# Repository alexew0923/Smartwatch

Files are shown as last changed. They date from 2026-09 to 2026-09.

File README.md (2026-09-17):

# Smartch
This repository contains all the files for the smartwatch and it is participating in the Stardance Challenge by Hack Club.

# Components Used
Components are bought from DigiKey, AliExpress and Amazon
- XIAO ESP32C3 (main processor)
- 450mAh LiPo Battery with PH 2.0 mm JST Connector
- PH 2.0 mm JST Connector
- 4 x 100nF 0603_1608 Capacitors (DigiKey part number: 1276-1005-1-ND)
- 1.28 inch Round TFT Display (with pin sockets)
- DS3231 RTC Module (with pin headers)
- 6 x 10k 0603_1608 Resistors (DigiKey part number: 311-10.0KHRCT-ND)
- 4 x 4.7k 0603_1608 Resistors (DigiKey part number: 311-4.70KHRCT-ND)
- 2 x Tactile Switches (DigiKey part number: P10851SCT-ND)
- SMD SHT40 Temp&Hum Sensor (DigiKey part number: 1649-SHT40-AD1F-R2CT-ND)
- SMD VEML6035 Ambient Light Sensor (DigiKey part number: VEML6035CT-ND)
- MPU6050 (with pin sockets)
- SMD BMP581 Air Pressure Sensor (DigiKey part number: 828-BMP581CT-ND)
- SMD CPT-9019A-SMT-TR Passive Buzzer (DigiKey part number: 2223-CPT-9019A-SMT-TRCT-ND)

## KiCad Designs
## Schematic
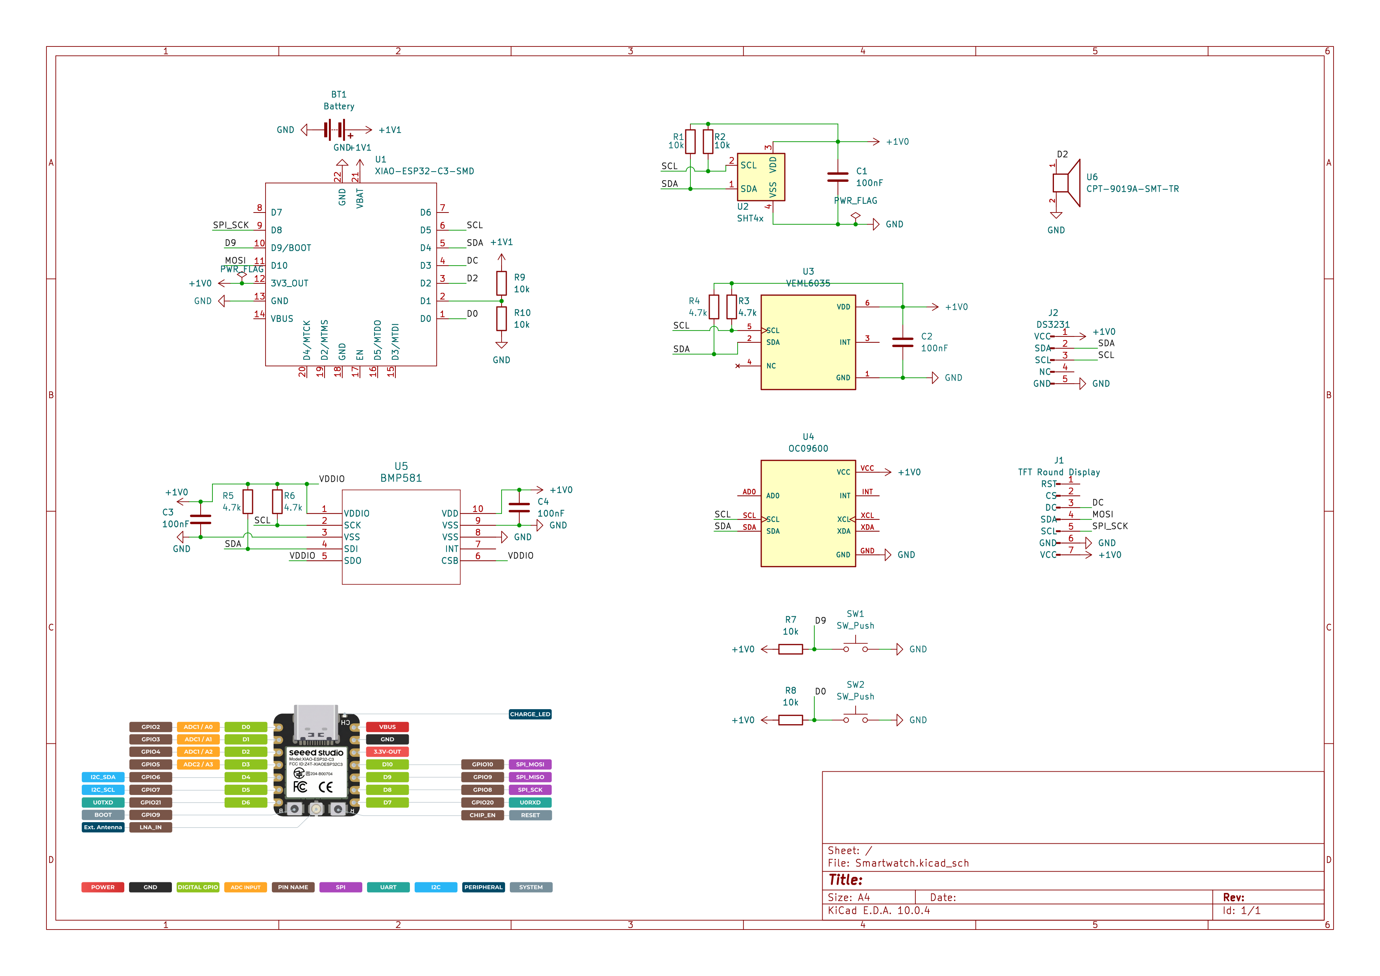
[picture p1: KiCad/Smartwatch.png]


## PCB
Use JLCPCB or other PCB fabrication services. If not using assembly option and soldering by yourself, by stencil and solder paste as well.

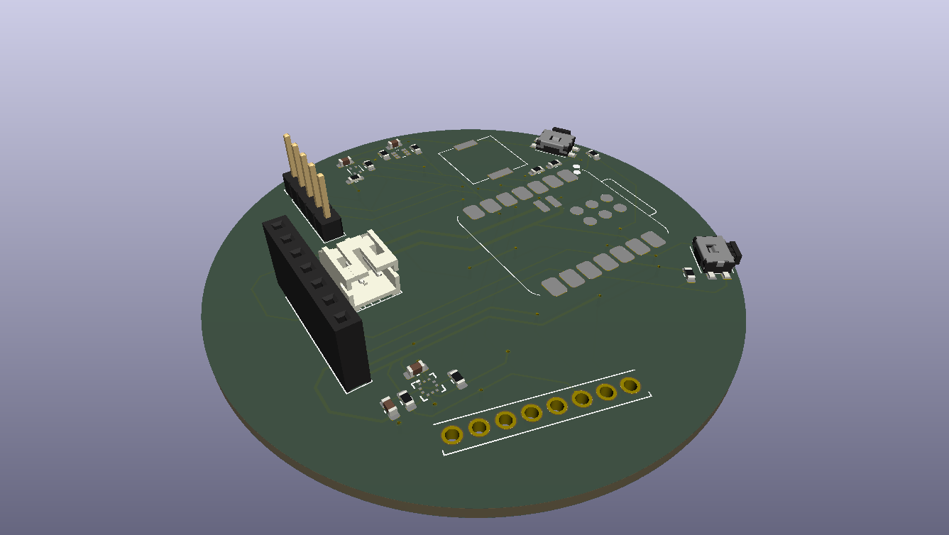
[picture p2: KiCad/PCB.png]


# Core Features
This smartwatch uses LVGL graphics library to develop user interface.

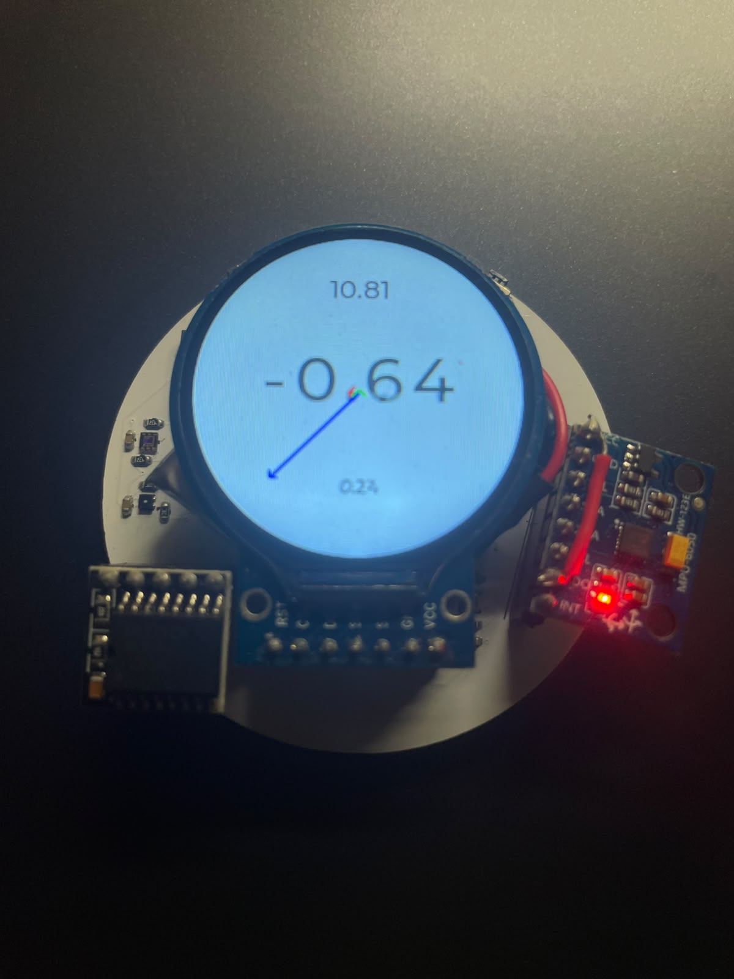
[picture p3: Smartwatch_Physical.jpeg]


## Current Features
1. Uses DS3231 RTC module, keeping time reliably even when the battery is dead.
2. Basic features in a clock app, such as stopwatch, timer and time adjustment.
3. Uses SHT40 sensor to log temperature on a graph.
4. Accelerometer & gyroscope readings and visualization.

## Upcoming Features
1. Alarm
2. Connect to the phone via Bluetooth to receive data such as weather, message, and news.
3. Automatic brightness adjustment with ambient light sensor.
4. Automatic screen saver with MPU6050.
5. Altitude reading and graph on BMP581.

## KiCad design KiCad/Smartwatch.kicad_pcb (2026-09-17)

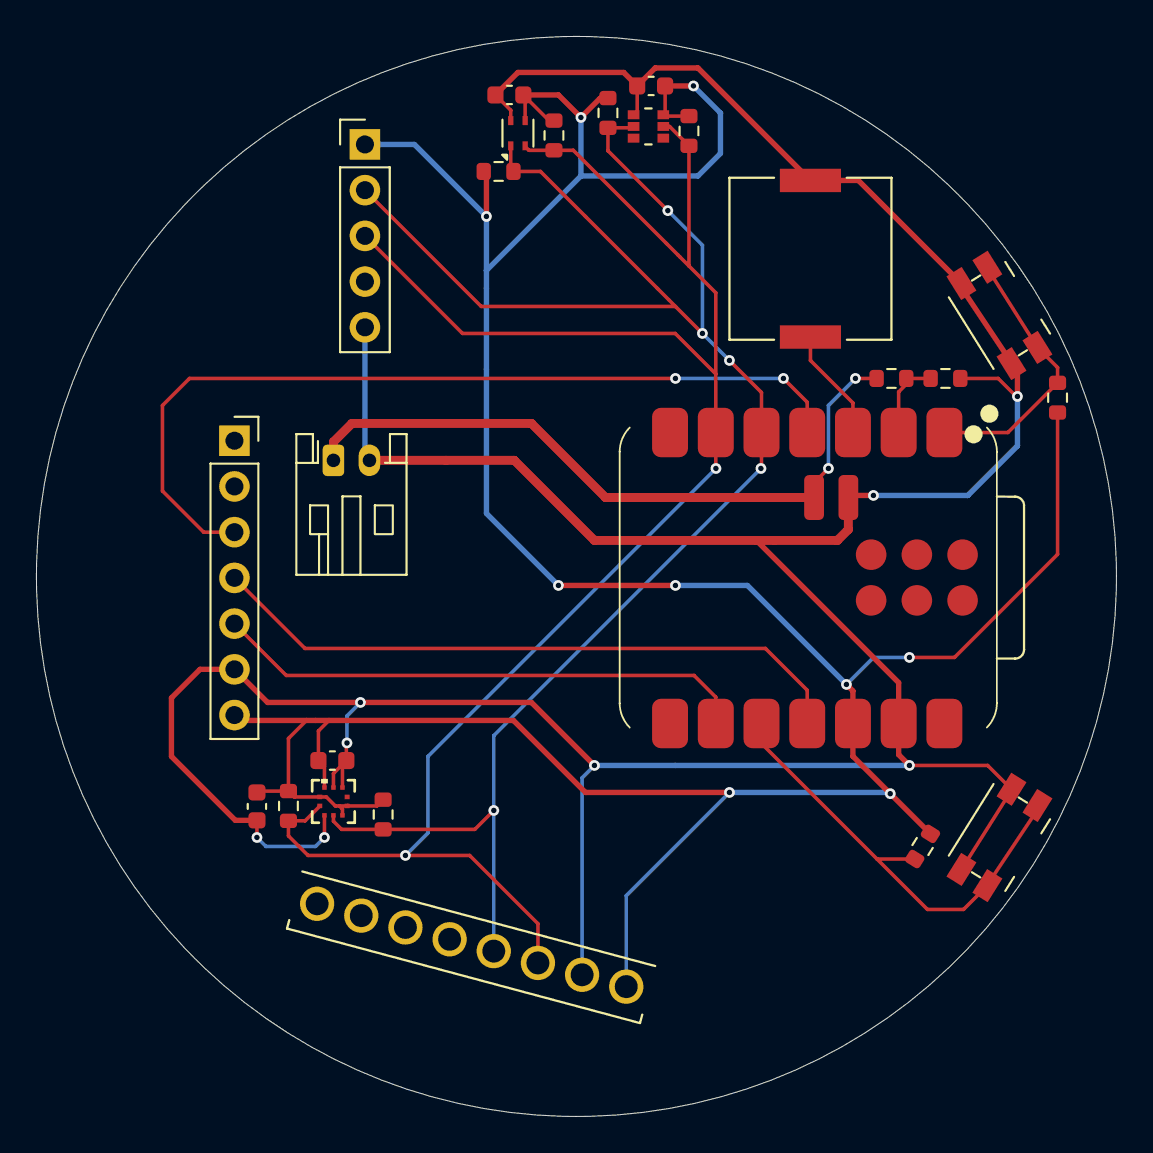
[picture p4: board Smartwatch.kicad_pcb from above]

Board: 2 copper layers, 60.0 x 60.0 mm, 25 parts (0 on the bottom side), 12 nets.

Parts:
BT1: Battery; JST_PH_S2B-PH-K_1x02_P2.00mm_Horizontal
C1, C2, C3, C4: 100nF; C_0603_1608Metric
J1: TFT Round Display; PinSocket_1x07_P2.54mm_Vertical
J2: DS3231; PinHeader_1x05_P2.54mm_Vertical
R1, R2, R7, R8, R9, R10: 10k; R_0603_1608Metric
R3, R4, R5, R6: 4.7k; R_0603_1608Metric
SW1, SW2: SW_Push; Panasonic_EVQPUJ_EVQPUA
U1: XIAO-ESP32-C3-SMD
U2: SHT4x; Sensirion_DFN-4_1.5x1.5mm_P0.8mm_SHT4x_NoCentralPad
U3: VEML6035; XDCR_VEML6035
U4: OC09600; MODULE_OC09600
U5: BMP581; QFN10_BMP581_BOS
U6: CPT-9019A-SMT-TR; XDCR_CPT-9019A-SMT-TR

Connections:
+1V0: C1.1, C2.1, C3.1, C4.1, J1.7 (VCC), J2.1 (VCC), R1.1, R2.2, R3.1, R4.1, R5.1, R6.1, R7.1, R8.1, U1.12 (3V3_OUT), U2.3 (VDD), U3.6 (VDD), U4.VCC, U5.1 (VDDIO), U5.5 (SDO), U5.6 (CSB), U5.10 (VDD)
+1V1: BT1.1 (+), R9.2, U1.21 (VBAT)
/D0: R8.2, SW2.1, U1.1 (D0)
/D2: U1.3 (D2), U6.1
/D9: R7.2, SW1.1, U1.10 (D9/BOOT)
/DC: J1.3 (DC), U1.4 (D3)
/MOSI: J1.4 (SDA), U1.11 (D10)
/SCL: J2.3 (SCL), R2.1, R3.2, R6.2, U1.6 (D5), U2.2 (SCL), U3.5 (SCL), U4.SCL, U5.2 (SCK)
/SDA: J2.2 (SDA), R1.2, R4.2, R5.2, U1.5 (D4), U2.1 (SDA), U3.2 (SDA), U4.SDA, U5.4 (SDI)
/SPI_SCK: J1.5 (SCL), U1.9 (D8)
GND: BT1.2 (-), C1.2, C2.2, C3.2, C4.2, J1.6 (GND), J2.5 (GND), R10.1, SW1.2, SW2.2, U1.13 (GND), U1.22 (GND), U2.4 (VSS), U3.1 (GND), U4.GND, U5.3 (VSS), U5.8 (VSS), U5.9 (VSS), U6.2
unnamed: R9.1, R10.2, U1.2 (D1)

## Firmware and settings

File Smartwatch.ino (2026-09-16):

//icons from Phosphor Icons
//https://notisrac.github.io/FileToCArray/ to convert icons to C array
#include <lvgl.h>
#include <TFT_eSPI.h>
#include "RTClib.h"
#include "Adafruit_SHT4x.h"
#include <Adafruit_MPU6050.h>
#include <Adafruit_Sensor.h>
#include <Wire.h>
#include "stopwatch.h"
#include "timer.h"
#include "temperature.h"
#include "gyroscope.h"

//Custom Icons
LV_IMG_DECLARE(STOPWATCH_ICON_INFO);
LV_IMG_DECLARE(TIMER_ICON_INFO);
LV_IMG_DECLARE(TEMP_ICON_INFO);
LV_IMG_DECLARE(GYRO_ICON_INFO);

//SHT40
Adafruit_SHT4x sht4 = Adafruit_SHT4x();

//MPU6050
Adafruit_MPU6050 mpu;

//DS3231
RTC_DS3231 rtc;
char daysOfTheWeek[7][12] = { "Sunday", "Monday", "Tuesday", "Wednesday", "Thursday", "Friday", "Saturday" };

int page = 0;
int app = -1;
int gyroMode = 0;

/*Set to your screen resolution and rotation*/
#define TFT_HOR_RES 240
#define TFT_VER_RES 240
#define TFT_ROTATION LV_DISPLAY_ROTATION_0

/*LVGL draw into this buffer, 1/10 screen size usually works well. The size is in bytes*/
#define DRAW_BUF_SIZE (TFT_HOR_RES * TFT_VER_RES / 10 * (LV_COLOR_DEPTH / 8))
uint32_t draw_buf[DRAW_BUF_SIZE / 4];

void my_print(lv_log_level_t level, const char *buf) {
  LV_UNUSED(level);
  Serial.println(buf);
  Serial.flush();
}

/* LVGL calls it when a rendered image needs to copied to the display*/
void my_disp_flush(lv_display_t *disp, const lv_area_t *area, uint8_t *px_map) {
  /*Copy `px map` to the `area`*/

  /*For example ("my_..." functions needs to be implemented by you)
  uint32_t w = lv_area_get_width(area);
  uint32_t h = lv_area_get_height(area);

  my_set_window(area->x1, area->y1, w, h);
  my_draw_bitmaps(px_map, w * h);
    */

  /*Call it to tell LVGL you are ready*/
  lv_display_flush_ready(disp);
}

/*use Arduinos millis() as tick source*/
static uint32_t my_tick(void) {
  return millis();
}

void setup() {
  //Button Pins
  pinMode(2, INPUT);
  pinMode(9, INPUT);
  ledcSetup(5, 131, 12);
  ledcAttachPin(4, 5);

  String LVGL_Arduino = "Hello Arduino! ";
  LVGL_Arduino += String('V') + lv_version_major() + "." + lv_version_minor() + "." + lv_version_patch();

  Serial.begin(115200);
  Serial.println(LVGL_Arduino);

  if (!sht4.begin()) {
    Serial.println("Couldn't find SHT4x");
    while (1) delay(1);
  }
  sht4.setPrecision(SHT4X_HIGH_PRECISION);
  sht4.setHeater(SHT4X_NO_HEATER);

  Wire.begin(6, 7);
  mpu.begin(0x69);
  mpu.setAccelerometerRange(MPU6050_RANGE_8_G);
  mpu.setGyroRange(MPU6050_RANGE_500_DEG);
  mpu.setFilterBandwidth(MPU6050_BAND_21_HZ);

  if (!rtc.begin()) {
    Serial.println("Couldn't find RTC");
    Serial.flush();
    while (1) delay(10);
  }

  if (rtc.lostPower()) {
    Serial.println("RTC lost power, let's set the time!");
    // When time needs to be set on a new device, or after a power loss, the
    // following line sets the RTC to the date & time this sketch was compiled
    rtc.adjust(DateTime(F(__DATE__), F(__TIME__)));
    // This line sets the RTC with an explicit date & time, for example to set
    // January 21, 2014 at 3am you would call:
    //rtc.adjust(DateTime(2014, 1, 21, 3, 0, 0));
  }

  lv_init();

  /*Set a tick source so that LVGL will know how much time elapsed. */
  lv_tick_set_cb(my_tick);

  lv_log_register_print_cb(my_print);

  lv_display_t *disp;
  /*TFT_eSPI can be enabled lv_conf.h to initialize the display in a simple way*/
  disp = lv_tft_espi_create(TFT_HOR_RES, TFT_VER_RES, draw_buf, sizeof(draw_buf));
  lv_display_set_rotation(disp, TFT_ROTATION);


  /* Create a simple label
    * ---------------------
    lv_obj_t *label = lv_label_create( lv_screen_active() );
    lv_label_set_text( label, "Hello Arduino, I'm LVGL!" );
    lv_obj_align( label, LV_ALIGN_CENTER, 0, 0 );

    * Try an example. See all the examples
    *  - Online: https://docs.lvgl.io/master/examples.html
    *  - Source codes: https://github.com/lvgl/lvgl/tree/master/examples
    * ----------------------------------------------------------------

    lv_example_btn_1();

    * Or try out a demo. Don't forget to enable the demos in lv_conf.h. E.g. LV_USE_DEMO_WIDGETS
    * -------------------------------------------------------------------------------------------

    lv_demo_widgets();
    */
  lv_obj_set_style_bg_color(lv_screen_active(), lv_color_hex(0xffffff), LV_PART_MAIN);
  widgetSetup();
  pageChange();
  setupHomepage();

  Serial.println("Setup done");
}

/*  When creating a new app, take the following steps
    1. Create new widgets if necessary
      1.1 Set up the initial setting of the widget in widgetSetup() 
      1.2 Edit pageChange() and appChange(), so that the new widget can be hidden accordingly
    2. Edit pageChange() and appChange() to decide what to show and hide
    3. Create a new page setup function to change the widgets' position, initial value, etc...
*/
//LVGL Widgets
lv_obj_t *label_time;
lv_obj_t *label_name;
lv_obj_t *label_date;
lv_obj_t *panel_name;
lv_obj_t *image_icon;
lv_obj_t *chart_temp;
lv_chart_series_t *ser_temp;
lv_obj_t *scale_temp;
lv_obj_t *acc_x_line;
lv_obj_t *acc_y_line;
lv_obj_t *acc_z_line;


void widgetSetup() {
  //chart: temp
  chart_temp = lv_chart_create(lv_screen_active());
  lv_obj_center(chart_temp);
  lv_chart_set_type(chart_temp, LV_CHART_TYPE_LINE);
  lv_chart_set_update_mode(chart_temp, LV_CHART_UPDATE_MODE_SHIFT);
  lv_obj_set_size(chart_temp, 200, 200);
  lv_chart_set_div_line_count(chart_temp, 6, 6);
  lv_obj_set_style_border_opa(chart_temp, LV_OPA_0, LV_PART_MAIN);
  lv_obj_set_style_pad_hor(chart_temp, 30, LV_PART_MAIN);
  ser_temp = lv_chart_add_series(chart_temp, lv_color_hex(0x000000), LV_CHART_AXIS_PRIMARY_Y);

  //label: time
  label_time = lv_label_create(lv_screen_active());
  lv_obj_set_align(label_time, LV_ALIGN_CENTER);
  lv_obj_set_style_text_align(label_time, LV_TEXT_ALIGN_CENTER, LV_PART_MAIN);
  lv_obj_set_style_text_line_space(label_time, 5, LV_PART_MAIN);

  //label: date
  label_date = lv_label_create(lv_screen_active());
  lv_obj_set_align(label_date, LV_ALIGN_CENTER);
  lv_obj_set_style_text_font(label_date, &lv_font_montserrat_20, LV_PART_MAIN);
  lv_obj_set_style_text_align(label_date, LV_TEXT_ALIGN_CENTER, LV_PART_MAIN);

  //panel: name
  panel_name = lv_obj_create(lv_screen_active());
  lv_obj_set_style_bg_color(panel_name, lv_color_hex(0x3f51b5), LV_PART_MAIN);
  lv_obj_set_style_border_opa(panel_name, LV_OPA_0, LV_PART_MAIN);
  lv_obj_set_style_radius(panel_name, 20, LV_PART_MAIN);
  lv_obj_set_align(panel_name, LV_ALIGN_CENTER);
  lv_obj_set_y(panel_name, 70);

  //label: name
  label_name = lv_label_create(lv_screen_active());
  lv_obj_set_align(label_name, LV_ALIGN_CENTER);
  lv_obj_set_y(label_name, 70);
  lv_obj_set_style_text_align(label_name, LV_TEXT_ALIGN_CENTER, LV_PART_MAIN);

  //image: icon
  image_icon = lv_image_create(lv_screen_active());
  lv_obj_align(image_icon, LV_ALIGN_CENTER, 0, -20);
  
  //scale: temp
  scale_temp = lv_scale_create(lv_screen_active());
  lv_obj_align(scale_temp, LV_ALIGN_CENTER, 85, 0);
  lv_scale_set_mode(scale_temp, LV_SCALE_MODE_VERTICAL_LEFT);
  lv_obj_set_size(scale_temp, 30, 200);
  lv_scale_set_label_show(scale_temp, true);
  lv_scale_set_total_tick_count(scale_temp, 13);
  lv_scale_set_major_tick_every(scale_temp, 3);
  lv_obj_set_style_length(scale_temp, 5, LV_PART_ITEMS);
  lv_obj_set_style_length(scale_temp, 10, LV_PART_INDICATOR);

  //line: acc_x
  acc_x_line = lv_line_create(lv_screen_active());
  lv_obj_set_size(acc_x_line, 240, 240);
  lv_obj_set_style_line_width(acc_x_line, 2, LV_PART_MAIN);
  lv_obj_set_style_line_color(acc_x_line, lv_color_hex(0xff0000), LV_PART_MAIN);

  //line: acc_y
  acc_y_line = lv_line_create(lv_screen_active());
  lv_obj_set_size(acc_y_line, 240, 240);
  lv_obj_set_style_line_width(acc_y_line, 2, LV_PART_MAIN);
  lv_obj_set_style_line_color(acc_y_line, lv_color_hex(0x00ff00), LV_PART_MAIN);
  
  //line: acc_z
  acc_z_line = lv_line_create(lv_screen_active());
  lv_obj_set_size(acc_z_line, 240, 240);
  lv_obj_set_style_line_width(acc_z_line, 2, LV_PART_MAIN);
  lv_obj_set_style_line_color(acc_z_line, lv_color_hex(0x0000ff), LV_PART_MAIN);
}

void pageChange() { //other than page 0, all other pages have the same format: icon, panel and a label
  if (page == 0) { //time
    setupHomepage();
    lv_obj_remove_flag(label_time, LV_OBJ_FLAG_HIDDEN);
    lv_obj_remove_flag(label_date, LV_OBJ_FLAG_HIDDEN);
    lv_obj_add_flag(image_icon, LV_OBJ_FLAG_HIDDEN);
  } else {
    setupPage();
    lv_obj_add_flag(label_time, LV_OBJ_FLAG_HIDDEN);
    lv_obj_add_flag(label_date, LV_OBJ_FLAG_HIDDEN);
    lv_obj_remove_flag(image_icon, LV_OBJ_FLAG_HIDDEN);
  }
  lv_obj_remove_flag(panel_name, LV_OBJ_FLAG_HIDDEN);
  lv_obj_remove_flag(label_name, LV_OBJ_FLAG_HIDDEN);
  lv_obj_add_flag(chart_temp, LV_OBJ_FLAG_HIDDEN);
  lv_obj_add_flag(scale_temp, LV_OBJ_FLAG_HIDDEN);
}


void setupHomepage() {
  //label: date
  lv_obj_set_y(label_date, -80);
  //label: time
  lv_obj_set_style_text_font(label_time, &lv_font_montserrat_48, LV_PART_MAIN); /*Set a larger font*/
  lv_obj_set_style_text_letter_space(label_time, 5, LV_PART_MAIN);
  lv_obj_set_y(label_time, -10);
  updateTime(0);
  //label: name
  lv_label_set_text(label_name, "Welcome, Eunwoo");
  //panel: name
  lv_obj_set_size(panel_name, 150, 35);
}


void setupPage() {
  if (page == 1) {
    //label: name
    lv_label_set_text(label_name, "Stopwatch");
    //panel: name
    lv_obj_set_size(panel_name, 95, 35);
    //image: icon
    lv_img_set_src(image_icon, &STOPWATCH_ICON_INFO);
  } else if (page == 2) {
    lv_label_set_text(label_name, "Timer");
    lv_obj_set_size(panel_name, 60, 35);
    lv_img_set_src(image_icon, &TIMER_ICON_INFO);
  } else if (page == 3) {
    lv_obj_set_size(panel_name, 115, 35);
    lv_label_set_text(label_name, "Temp & Hum");
    lv_img_set_src(image_icon, &TEMP_ICON_INFO);
  } else if (page == 4) {
    lv_obj_set_size(panel_name, 115, 35);
    lv_label_set_text(label_name, "Acc & Gyro");
    lv_img_set_src(image_icon, &GYRO_ICON_INFO);
  }
}

void appChange() {
  if (app == 0) { //time
    setupHomeApp();
    lv_obj_remove_flag(label_time, LV_OBJ_FLAG_HIDDEN);
    lv_obj_add_flag(label_name, LV_OBJ_FLAG_HIDDEN);
    lv_obj_add_flag(label_date, LV_OBJ_FLAG_HIDDEN);
    lv_obj_add_flag(panel_name, LV_OBJ_FLAG_HIDDEN);
    lv_obj_add_flag(image_icon, LV_OBJ_FLAG_HIDDEN);
    lv_obj_add_flag(chart_temp, LV_OBJ_FLAG_HIDDEN);
    lv_obj_add_flag(scale_temp, LV_OBJ_FLAG_HIDDEN);
  } else if (app == 1) { //stopwatch
    setupStopwatchApp();
    lv_obj_remove_flag(label_time, LV_OBJ_FLAG_HIDDEN);
    lv_obj_add_flag(label_name, LV_OBJ_FLAG_HIDDEN);
    lv_obj_add_flag(label_date, LV_OBJ_FLAG_HIDDEN);
    lv_obj_add_flag(panel_name, LV_OBJ_FLAG_HIDDEN);
    lv_obj_add_flag(chart_temp, LV_OBJ_FLAG_HIDDEN);
    lv_obj_add_flag(image_icon, LV_OBJ_FLAG_HIDDEN);
    lv_obj_add_flag(scale_temp, LV_OBJ_FLAG_HIDDEN);
  } else if (app == 2) { //timer
    setupTimerApp();
    lv_obj_remove_flag(label_time, LV_OBJ_FLAG_HIDDEN);
    lv_obj_add_flag(label_name, LV_OBJ_FLAG_HIDDEN);
    lv_obj_add_flag(label_date, LV_OBJ_FLAG_HIDDEN);
    lv_obj_add_flag(panel_name, LV_OBJ_FLAG_HIDDEN);
    lv_obj_add_flag(chart_temp, LV_OBJ_FLAG_HIDDEN);
    lv_obj_add_flag(image_icon, LV_OBJ_FLAG_HIDDEN);
    lv_obj_add_flag(scale_temp, LV_OBJ_FLAG_HIDDEN);
  } else if (app == 3) { //temperature
    setupTempApp();
    lv_obj_remove_flag(label_time, LV_OBJ_FLAG_HIDDEN);
    lv_obj_add_flag(label_name, LV_OBJ_FLAG_HIDDEN);
    lv_obj_add_flag(label_date, LV_OBJ_FLAG_HIDDEN);
    lv_obj_add_flag(panel_name, LV_OBJ_FLAG_HIDDEN);
    lv_obj_remove_flag(chart_temp, LV_OBJ_FLAG_HIDDEN);
    lv_obj_remove_flag(scale_temp, LV_OBJ_FLAG_HIDDEN);
    lv_obj_add_flag(image_icon, LV_OBJ_FLAG_HIDDEN);
  } else if (app == 4) { //accelerometer & gyroscope
    lv_obj_remove_flag(label_time, LV_OBJ_FLAG_HIDDEN);
    lv_obj_remove_flag(label_name, LV_OBJ_FLAG_HIDDEN);
    lv_obj_remove_flag(label_date, LV_OBJ_FLAG_HIDDEN);
    lv_obj_add_flag(panel_name, LV_OBJ_FLAG_HIDDEN);
    lv_obj_add_flag(chart_temp, LV_OBJ_FLAG_HIDDEN);
    lv_obj_add_flag(scale_temp, LV_OBJ_FLAG_HIDDEN);
    lv_obj_add_flag(image_icon, LV_OBJ_FLAG_HIDDEN);
  }
}

void setupHomeApp() {
  //label: time
  lv_obj_set_y(label_time, 0);
}

void setupStopwatchApp() {
  //label: time
  lv_obj_set_style_text_font(label_time, &lv_font_montserrat_44, LV_PART_MAIN); /*Set a larger font*/
  lv_obj_set_style_text_letter_space(label_time, 0, LV_PART_MAIN);
  lv_label_set_text(label_time, "00:00:00");
  lv_obj_set_y(label_time, 0);
}

void setupTimerApp() {
  //label: time
  lv_obj_set_style_text_font(label_time, &lv_font_montserrat_44, LV_PART_MAIN); /*Set a larger font*/
  lv_obj_set_style_text_letter_space(label_time, 0, LV_PART_MAIN);
  lv_label_set_text(label_time, "00:00:00");
  lv_obj_set_y(label_time, 0);
}

void setupTempApp() {
  updateTempChart();

  //label: time
  lv_obj_set_style_text_font(label_time, &lv_font_montserrat_20, LV_PART_MAIN);
  lv_obj_set_style_text_letter_space(label_time, 0, LV_PART_MAIN);
  lv_obj_set_y(label_time, 70);
}


void updateTempChart() {
  int temp_max = -10000;
  int temp_min = 10000;
  int32_t *temp_arr = lv_chart_get_series_y_array(chart_temp, ser_temp);
  for (int i = 0; i < 10; i++) {
    int temp_arr_val = *(temp_arr + i);
    Serial.println(temp_arr_val);
    if (-10000 < temp_arr_val && temp_arr_val < 10000) {
      lv_label_set_text_fmt(label_time, "%i°C", temp_arr_val);
      if (temp_arr_val > temp_max) {
        temp_max = temp_arr_val;
      }
      if (temp_arr_val < temp_min) {
        temp_min = temp_arr_val;
      }
    }
  }

  int buffer = (temp_max - temp_min) * 0.1;
  temp_max += buffer;
  temp_min -= buffer;
  Serial.println(temp_max);
  Serial.println(temp_min);
  lv_chart_set_axis_range(chart_temp, LV_CHART_AXIS_PRIMARY_Y, temp_min, temp_max);
  lv_scale_set_range(scale_temp, temp_min, temp_max);
}

DateTime now;

void updateTime(int minute) {
  // Get the current time from the RTC
  now = rtc.now();

  if (minute != 0) {
    int newMinute = now.minute() + minute;
    if (newMinute < 0) {
      rtc.adjust(DateTime(now.year(), now.month(), now.day(), now.hour() - 1, 59, 0));
    } else if (newMinute > 59) {
      rtc.adjust(DateTime(now.year(), now.month(), now.day(), now.hour() + 1, 0, 0));
    } else {
      rtc.adjust(DateTime(now.year(), now.month(), now.day(), now.hour(), newMinute, 0));
    }
  }

  // Getting each time field in individual variables
  // And adding a leading zero when needed;
  String yearStr = String(now.year(), DEC);
  String monthStr = (now.month() < 10 ? "0" : "") + String(now.month(), DEC);
  String dayStr = (now.day() < 10 ? "0" : "") + String(now.day(), DEC);
  String hourStr = (now.hour() < 10 ? "0" : "") + String(now.hour(), DEC);
  String minuteStr = (now.minute() < 10 ? "0" : "") + String(now.minute(), DEC);
  String secondStr = (now.second() < 10 ? "0" : "") + String(now.second(), DEC);
  String dayOfWeek = daysOfTheWeek[now.dayOfTheWeek()];

  // Complete time string
  String formattedTime = dayOfWeek + ", " + yearStr + "-" + monthStr + "-" + dayStr + " " + hourStr + ":" + minuteStr + ":" + secondStr;

  // Print the complete formatted time
  Serial.println(formattedTime);

  lv_label_set_text_fmt(label_time, "%02u\n%02u", now.hour(), now.minute());
  lv_label_set_text_fmt(label_date, "%u-%02u-%02u", now.year(), now.month(), now.day());
}


bool stopwatchOn = false;
long stopwatchTime;

void updateStopwatch() {
  if (stopwatchTime == 0) {
    lv_label_set_text(label_time, "00:00:00");
  } else {
    unsigned long tempTime = millis() - stopwatchTime;
    uint8_t milliSecond = (tempTime/10)%100;
    uint8_t second = (tempTime/1000)%60;
    uint8_t minute = (tempTime/1000)/60;

    lv_label_set_text_fmt(label_time, "%02u:%02u:%02u", minute, second, milliSecond);
  }
}


bool timerOn = false;
unsigned long timerTime;
unsigned long timerStartTime;
unsigned long beepTime;
bool beepOn;

void updateTimer() {
  unsigned long tempTime = timerTime;

  if (timerOn) {
    if (millis() - timerStartTime > tempTime) {
      tempTime = 0;
      if (millis() - beepTime > 500) {
        if (!beepOn) {
          ledcWrite(5, 0);
        } else {
          ledcWrite(5, 2048);
        }
        beepOn = !beepOn;
        beepTime = millis();
      }
    } else {
      tempTime -= millis() - timerStartTime;
    }
  }

  uint8_t second = (tempTime/1000)%60;
  uint8_t minute = (tempTime/60000)%60;
  uint8_t hour = (tempTime/3600000);

  lv_label_set_text_fmt(label_time, "%02u:%02u:%02u", hour, minute, second);
}


struct previousMillis {
  unsigned long lvgl;
  unsigned long time;
  unsigned long timeFlicker;
  unsigned long temp;
  unsigned long gyro;
};
previousMillis prevMillis;

struct buttonSetting {
  unsigned long time = 0;
  bool previous = false;
  bool next = false;
  bool both = false;
};
buttonSetting button;


void loop() {
  if (digitalRead(2) == LOW && digitalRead(9) == LOW) {
    if (app == 2 && !button.both) {
      timerOn = true;
      timerStartTime = millis();
      button.previous = false;
      button.next = false;
      button.both = true;
    }
  } else if (digitalRead(2) == LOW) {
    if (!button.previous && !button.both) {
      button.previous = true;
      button.time = millis();
    }
  } else if (digitalRead(9) == LOW) {
    if (!button.next && !button.both) {
      button.next = true;
      button.time = millis();
    }
  } else {
    button.both = false;
    if (button.previous) {
      Serial.println("Previous");
      button.previous = false;
      if (millis() - button.time > 500) {
        Serial.print("Entering App");
        app = page;
        appChange();
      } else {
        if (app == -1) {
          page--;
          pageChange();
        } else if (app == 0) {
          updateTime(1);
        } else if (app == 1) {
          if (!stopwatchOn) {
            stopwatchOn = true;
          } else {
            stopwatchOn = false;
          }
          stopwatchTime = millis() - stopwatchTime;
        } else if (app == 2) {
          if (timerOn) {
            timerOn = false;
            if (millis() - timerStartTime > timerTime) {
              timerTime = 0;
            } else {
              timerTime -= millis() - timerStartTime;
            }
          } else {
            timerTime += 1000;
          }
        }
      }
    }
    if (button.next) {
      Serial.println("Next");
      button.next = false;
      if (millis() - button.time > 500) {
        Serial.print("Exiting App");
        app = -1;
        pageChange();
      } else {
        if (app == -1) {
          page++;
          pageChange();
        } else if (app == 0) {
          updateTime(-1);
        } else if (app == 1 && !stopwatchOn) {
          stopwatchTime = 0;
          updateStopwatch();
        } else if (app == 2) {
          if (!timerOn) {
            if (timerTime > 1000) {
              timerTime -= 1000;
            } else {
              timerTime = 0;
            }
          }
        } else if (app == 3) {

        } else if (app == 4) {
          if (gyroMode < 1) {
            gyroMode++;
          } else {
            gyroMode = 0;
          }
        }
      }
    }
  }

  if ((page == 0 or app == 0) && millis() - prevMillis.time > 500) {
    updateTime(0);
    prevMillis.time = millis();
  }

  if (app == 0 && millis() - prevMillis.timeFlicker > 1000) {
    if (lv_obj_has_flag(label_time, LV_OBJ_FLAG_HIDDEN)) {
      lv_obj_remove_flag(label_time, LV_OBJ_FLAG_HIDDEN);
    } else {
      lv_obj_add_flag(label_time, LV_OBJ_FLAG_HIDDEN);
    }
    prevMillis.timeFlicker = millis();
  }

  if (app == 1 && stopwatchOn) {
    updateStopwatch();
  }

  if (app == 2) {
    updateTimer();
  }

  if (millis() - prevMillis.temp > 5000) {
    sensors_event_t humidity, temp;
    sht4.getEvent(&humidity, &temp);
    lv_chart_set_next_value(chart_temp, ser_temp, temp.temperature * 100);
    if (app == 3) {
      updateTempChart();
    }
    prevMillis.temp = millis();
  }

  if (app == 4) {
    sensors_event_t a, g, temp;
    mpu.getEvent(&a, &g, &temp); 
    int x, y, z;
    bool left, top, front;
    if (gyroMode == 0) {
      x = 120+120*a.acceleration.x/10;
      y = 120-120*a.acceleration.y/10;
      z = 60*a.acceleration.z/10;
      left = a.acceleration.x > 0;
      top = a.acceleration.y > 0;
      front = a.acceleration.z > 0;

      lv_label_set_text_fmt(label_time, "%.2f", a.acceleration.x);
      lv_label_set_text_fmt(label_name, "%.2f", a.acceleration.y);
      lv_label_set_text_fmt(label_date, "%.2f", a.acceleration.z);
    } else if (gyroMode == 1) {
      x = 120+120*g.gyro.x/15;
      y = 120-120*g.gyro.y/15;
      z = 60*g.gyro.z/15;
      left = g.gyro.x > 0;
      top = g.gyro.y > 0;
      front = g.gyro.z > 0;

      lv_label_set_text_fmt(label_time, "%.2f", g.gyro.x);
      lv_label_set_text_fmt(label_name, "%.2f", g.gyro.y);
      lv_label_set_text_fmt(label_date, "%.2f", g.gyro.z);
    
    }

    lv_point_precise_t x_line_points[] = {{120, 120}, {x, 120}, {x+5-10*left, 115}, {x, 120}, {x+5-10*left, 125}}; //draws line and arrow
    lv_point_precise_t y_line_points[] = {{120, 120}, {120, y}, {115, y-5+10*top}, {120, y}, {125, y-5+10*top}};
    lv_point_precise_t z_line_points[] = {{120, 120}, {120 - z, 120 + z}, {120-z, 120+z+6-12*front}, {120 - z, 120 + z}, {120-z-6+12*front, 120+z}};
    lv_line_set_points(acc_x_line, x_line_points, 5);
    lv_line_set_points(acc_y_line, y_line_points, 5);
    lv_line_set_points(acc_z_line, z_line_points, 5);
  }

  if (millis() - prevMillis.lvgl > 5) {
    lv_timer_handler(); /* let the GUI do its work */
    prevMillis.lvgl = millis();
  }
}

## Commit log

2026-09-09 Passive buzzer noise fix Code optimization Edit time
    [Smartwatch.ino]
2026-09-16 Gyro & Accel. Update
2026-11-01 added air pressure app
2026-11-01 battery voltage range change
